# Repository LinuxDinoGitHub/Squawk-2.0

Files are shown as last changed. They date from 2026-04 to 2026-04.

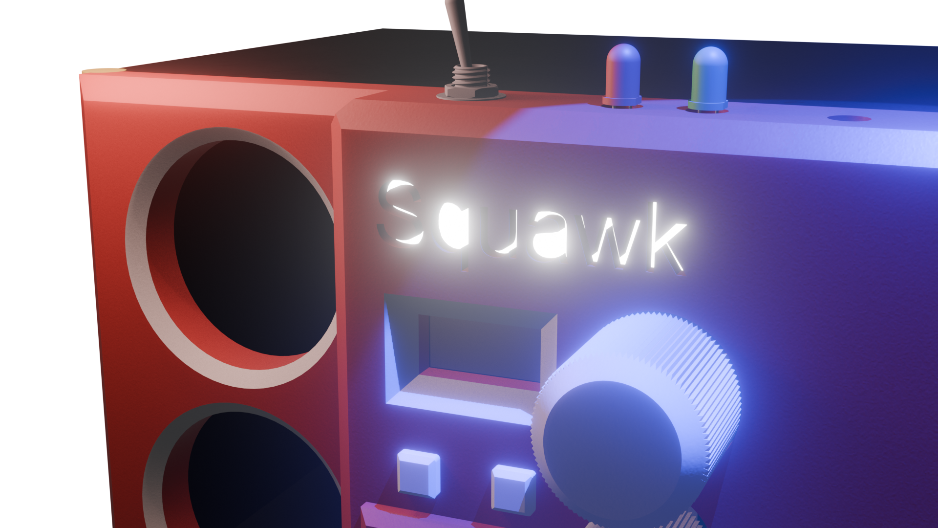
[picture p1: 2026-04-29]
Assets/Radio_corner.png

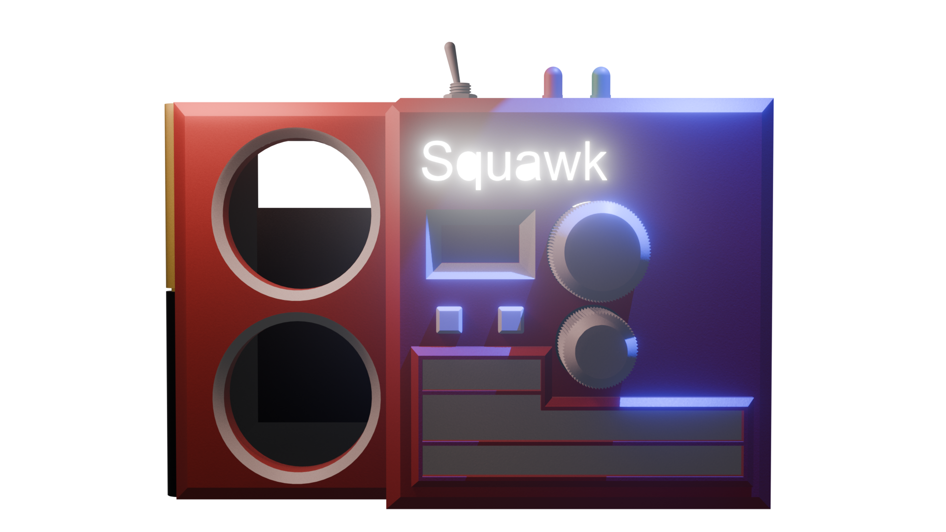
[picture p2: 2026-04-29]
Assets/Radio_front.png

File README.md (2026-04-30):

# Squawk-2.0
A radio station with a storage unit for walkie-talkies, w/ OLED screen & 3.5mm headphone jack connector
SI4844 powered with Arduino Nano, PAM8403 amplifier with the [pu2clr](https://pu2clr.github.io/SI4844/) library.

Radio-2026-04-28 000101
Radio-2026-04-28 000112

## About this project
The name "Squawk 2.0" originates from the popular TV show - Stranger Things (Season 5), where they had a master radio station for duplex transmission. Though this station cannot transmit any radio signals for walkie-talkies to pick up (due to legal reasons), it listens to the Citizens Band (CB) with 20 channels and a range of 2-3km. This is designed as a retro tabletop AM/FM/SW radio with the SI4844 chip, and also a handy storage device for the user. Planning to create walkie-talkies in the future that can connect to this station.
### Why did I make this?
Well, I needed a storage compartment for my walkie talkies and also wanted the container to be a bit more exciting than just a regular tin box. 

### How do you use it?
It's pretty simple, here is a layout of all the functions of the buttons you can press:


## Key features
- SW/MW/AM/FM radio broadcast with SI4844 IC
- Adjustable channel and volume with OLED screen indicator
- Storage compartment in 3D model
- Hinged door to access the compartment
- Arduino powered - open source code and customisable to your own liking
- USB-B connectivity
- 3.5mm headphone jack to listen to the radio independently without interrupting neighbours, like a Walkman
- Optimised 4-layer PCB (front, gnd_front, gnd_back, back) routing for good antenna connectivity

## [Schematic](https://github.com/LinuxDinoGitHub/Squawk-2.0/tree/main/pcb)
Print Schematic

## [PCB](https://github.com/LinuxDinoGitHub/Squawk-2.0/tree/main/pcb)
A simple, 4-layer PCB. 96mm x 81mm PCB with 3 mounting holes for M3 screws.
### First layer (Front)


### Second layer (GND net)


### Third layer (GND net)


### Fourth layer (Back)


### 3D view
Front

Back


## [Firmware](https://github.com/LinuxDinoGitHub/Squawk-2.0/blob/main/firmware/firmware.ino)
After assembling your PCB, use the firmware.ino file in the repository to flash your Arduino Nano. You can customise messages and timings by editing the code with the Arduino IDE.

## BOM
The BOM **without** specific values is linked here ([GitHub directory](https://github.com/LinuxDinoGitHub/Squawk-2.0/blob/main/BOM_kicad_generated.csv) or [Google Sheets](https://docs.google.com/spreadsheets/d/1nt2ZC4SuuWCHXpdcqgjWmxoxNzFQoS0aQbvXVXabcSM/edit?gid=0#gid=0). The total cost for the project should not exceed 13USD (after averaging costs out by dividing by the bulk bought quantity).

The BOM **with** specific values is here (Github [directory](https://github.com/LinuxDinoGitHub/Squawk-2.0/blob/main/BOM_with_links.csv) or [Google Sheets](https://docs.google.com/spreadsheets/d/1nt2ZC4SuuWCHXpdcqgjWmxoxNzFQoS0aQbvXVXabcSM/edit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))

### 3D printed case
Use a slicer to print the following [file](https://github.com/LinuxDinoGitHub/Squawk-2.0/blob/main/models/Radio.step). The 3D printed case is not accounted for in the BOM due to the variation between suppliers. The expected filament cost is around 10$ USD.

## Zine page


## Credits
Huge thanks to Ricardo for his amazing library and intuitive example code for the SI4844, which genuinely saved me so much time. [Link](https://pu2clr.github.io/SI4844/) to his repo and library. Thanks to the amazing community from Hack Club fallout for helping out my design as well, I couldn't have done it without them.

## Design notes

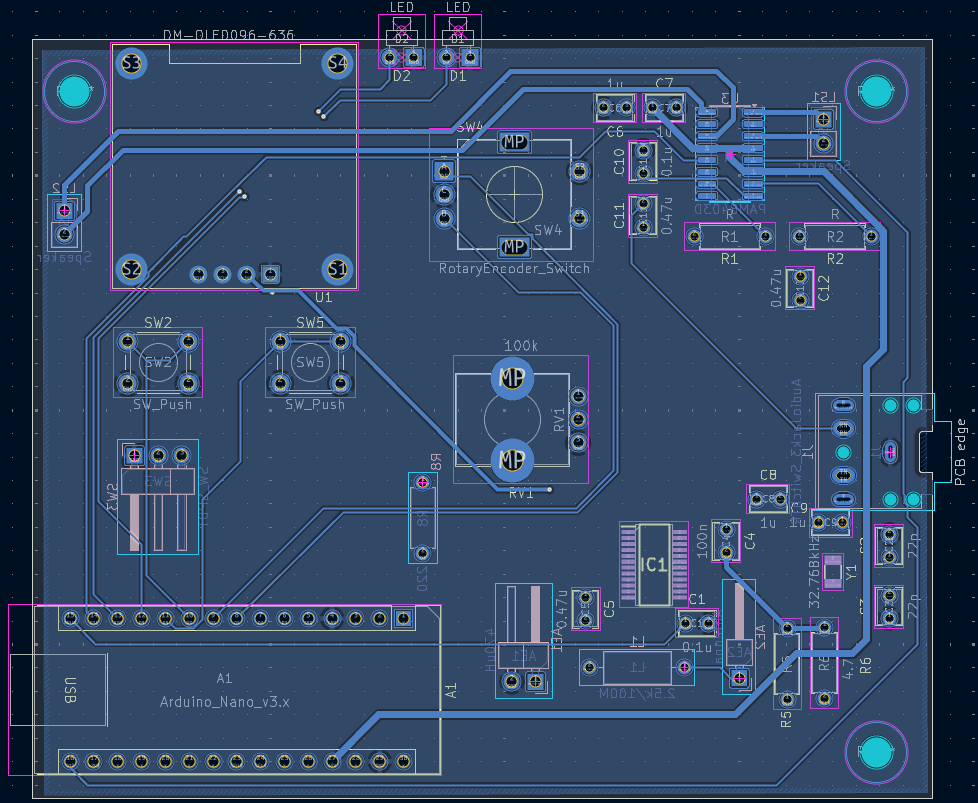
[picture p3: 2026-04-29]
Assets/Screenshot 2026-04-27 235309.png

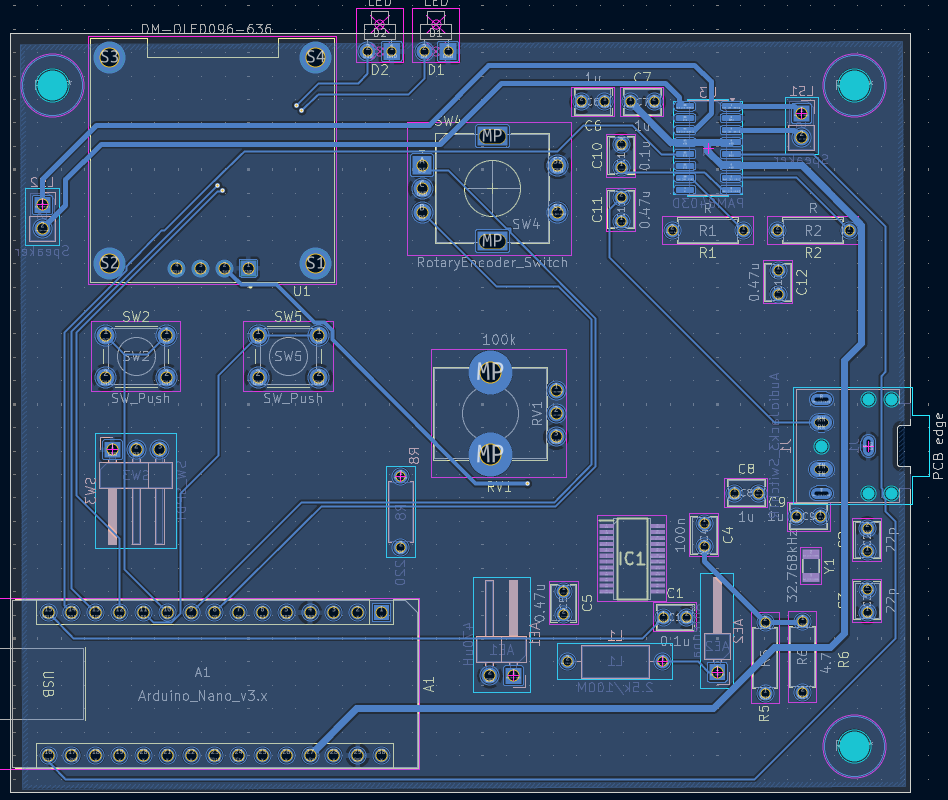
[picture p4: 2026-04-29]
Assets/Screenshot 2026-04-27 235300.png

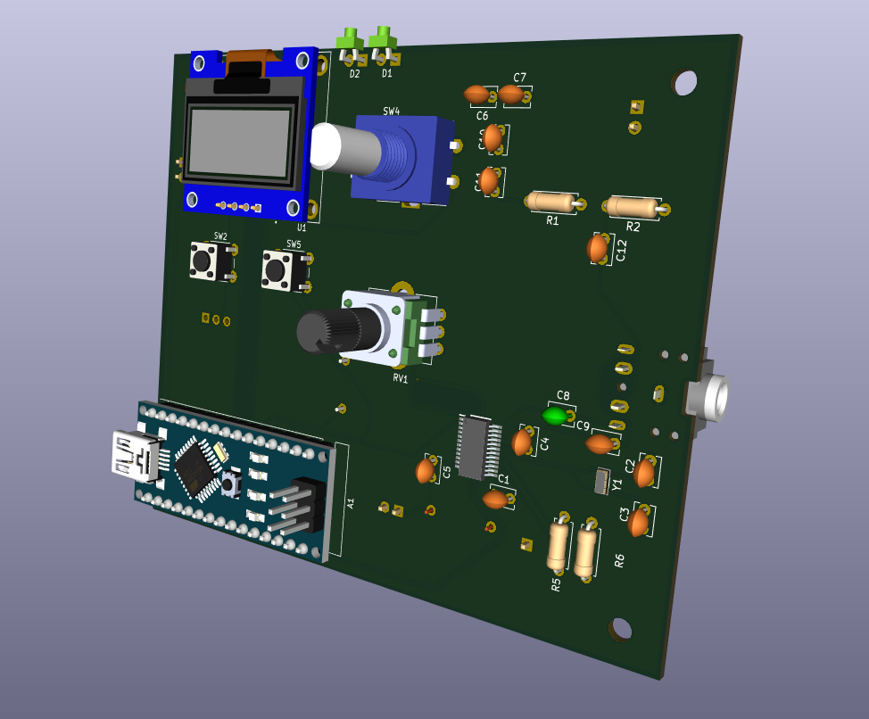
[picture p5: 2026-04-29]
Assets/Screenshot 2026-04-27 235516.png

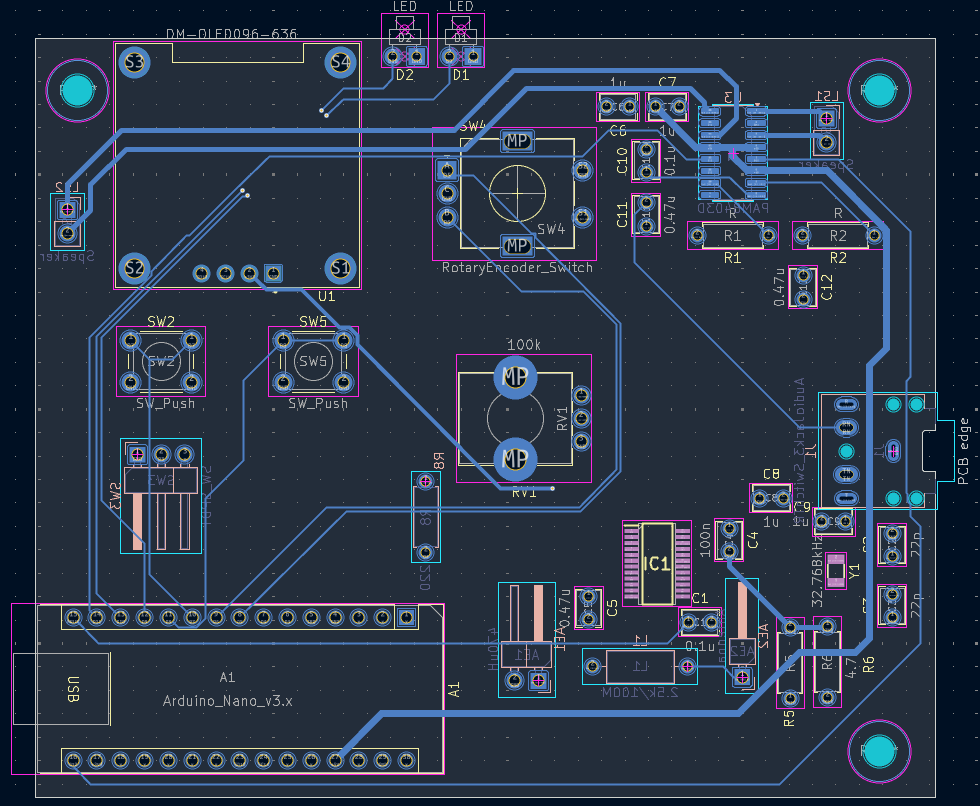
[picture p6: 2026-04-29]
Assets/Screenshot 2026-04-27 235333.png

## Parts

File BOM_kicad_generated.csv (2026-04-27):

Reference | Qty | Value | DNP | Exclude from BOM | Exclude from Board | Footprint | Datasheet
A1 | 1 | Arduino_Nano_v3.x |  |  |  | Module:Arduino_Nano | http://www.mouser.com/pdfdocs/Gravitech_Arduino_Nano3_0.pdf
AE1 | 1 | 470uH |  |  |  | Connector_PinHeader_2.54mm:PinHeader_1x02_P2.54mm_Horizontal
AE2 | 1 | Antenna |  |  |  | Connector_PinHeader_2.54mm:PinHeader_1x01_P2.54mm_Horizontal
C1,C10 | 2 | 0.1u |  |  |  | Capacitor_THT:C_Disc_D3.8mm_W2.6mm_P2.50mm
C2,C3 | 2 | 22p |  |  |  | Capacitor_THT:C_Disc_D3.8mm_W2.6mm_P2.50mm
C4 | 1 | 100n |  |  |  | Capacitor_THT:C_Disc_D3.8mm_W2.6mm_P2.50mm
C5,C11,C12 | 3 | 0.47u |  |  |  | Capacitor_THT:C_Disc_D3.8mm_W2.6mm_P2.50mm
C6,C7,C8,C9 | 4 | 1u |  |  |  | Capacitor_THT:C_Disc_D3.8mm_W2.6mm_P2.50mm
D1,D2 | 2 | LED |  |  |  | LED_THT:LED_D1.8mm_W1.8mm_H2.4mm_Horizontal_O1.27mm_Z1.6mm
IC1 | 1 | SI4844-B20-GUR |  |  |  | KiCad2:SOP64P600X175-24N | https://www.mouser.com/datasheet/2/472/Si4844_B20-2507496.pdf
J1 | 1 | AudioJack3_SwitchTR |  |  |  | Connector_Audio:Jack_3.5mm_CUI_SJ1-3525N_Horizontal
L1 | 1 | 2.5k/100M |  |  |  | Inductor_THT:L_Axial_L7.0mm_D3.3mm_P10.16mm_Horizontal_Fastron_MICC
LS1,LS2 | 2 | Speaker |  |  |  | Connector_PinHeader_2.54mm:PinHeader_1x02_P2.54mm_Vertical
R1,R2 | 2 | R |  |  |  | Resistor_THT:R_Axial_DIN0207_L6.3mm_D2.5mm_P7.62mm_Horizontal
R5,R6 | 2 | 4.7k |  |  |  | Resistor_THT:R_Axial_DIN0207_L6.3mm_D2.5mm_P7.62mm_Horizontal
R8 | 1 | 220 |  |  |  | Resistor_THT:R_Axial_DIN0207_L6.3mm_D2.5mm_P7.62mm_Horizontal
RV1 | 1 | 100k |  |  |  | Potentiometer_THT:Potentiometer_Bourns_PTV09A-1_Single_Vertical
SW2,SW5 | 2 | SW_Push |  |  |  | Button_Switch_THT:SW_PUSH_6mm
SW3 | 1 | SW_SPDT |  |  |  | Connector_PinHeader_2.54mm:PinHeader_1x03_P2.54mm_Horizontal
SW4 | 1 | RotaryEncoder_Switch |  |  |  | Rotary_Encoder:RotaryEncoder_Alps_EC11E-Switch_Vertical_H20mm
U1 | 1 | DM-OLED096-636 |  |  |  | DM-OLED096-636:MODULE_DM-OLED096-636
U3 | 1 | PAM8403D |  |  |  | Package_SO:SOIC-16_3.9x9.9mm_P1.27mm | https://www.diodes.com/assets/Datasheets/products_inactive_data/PAM8403.pdf
Y1 | 1 | 32.768kHz |  |  |  | Crystal:Crystal_SMD_3215-2Pin_3.2x1.5mm

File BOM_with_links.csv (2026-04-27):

Component | Quantity | Purchasing quantity | Price (HKD) | Average Price(HKD) | Link (Aliexpress)
Arduino nano | 1 | 1 | 15.63 | 15.63 | https://www.aliexpress.com/item/1005004904865598.html?curPageLogUid=vkYqpu5df7i1
Si4844 | 1 | 1 | 6.22 | 6.22 | https://www.aliexpress.com/item/1005009167191304.html?curPageLogUid=VBaIWKYVAlcq
Speaker | 2 | 2 | 14.69 | 14.69 | https://www.aliexpress.com/item/32963121430.html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
Audio jack | 1 | 10 | 13.21 | 1.32 | https://www.aliexpress.com/item/1005008243857446.html?curPageLogUid=lKPTrOS0Pi5D
Audio amp | 1 | 10 | 1.41 | 0.14 | https://www.aliexpress.com/item/1005004049958533.html?curPageLogUid=BbQga2S7KLyP
Ferrite rod antenna | 1 | 5 | 50.6 | 10.12 | https://www.aliexpress.com/item/4000125449068.html?scm_id=1007.40050.354490.0&scm-url=1007.40050.354490.0
FM antenna | 1 | 1 | 8.73 | 8.73 | https://www.aliexpress.com/item/1005004492932391.html?curPageLogUid=ljO8rNIAne0f
6mm tactile switch | 2 | 20 | 7 | 0.70 | https://www.aliexpress.com/item/33008621978.html?curPageLogUid=k7zHfLOsFU2o
5mm LEDs | 2 | 100 | 9.68 | 0.19 | https://www.aliexpress.com/item/1005008232913389.html?curPageLogUid=16FXfKzrMASL
Toggle switch | 1 | 1 | 3.85 | 3.85 | https://www.aliexpress.com/item/4000177976189.html?curPageLogUid=18NpcsBhdBTf
Variable resistor | 1 | 10 | 3.22 | 0.32 | https://www.aliexpress.com/item/1005003276146441.html?curPageLogUid=0bzzIlN6npLy
OLED Display 0.96 inch | 1 | 1 | 9.99 | 9.99 | https://www.aliexpress.com/item/1005006385950490.html?curPageLogUid=9HJrmzL4Pr96
Resistors | 10 | 300 | 16.15 | 0.54 | https://www.aliexpress.com/item/1005011772534173.html?curPageLogUid=68fhdKCqYf9S
Capacitors (0.1u, 22p, 100n, 0.47u, 1u) | 12 | 500 | 40.2 | 0.96 | https://www.aliexpress.com/item/1005002513813451.html?curPageLogUid=eFP2b91R6ocB
Rotary encoder | 1 | 1 | 4.88 | 4.88 | https://www.aliexpress.com/item/1005007644083514.html?curPageLogUid=689RurIsD01g
Crystal 32.768kHz | 1 | 10 | 5.74 | 0.57 | https://www.aliexpress.com/item/1005004765596465.html?curPageLogUid=2FnkTeJsL6hJ
PCB (no shipping) | 1 | 5 | 54.6 | 10.92
Total |  |  | 211.2 | 89.78

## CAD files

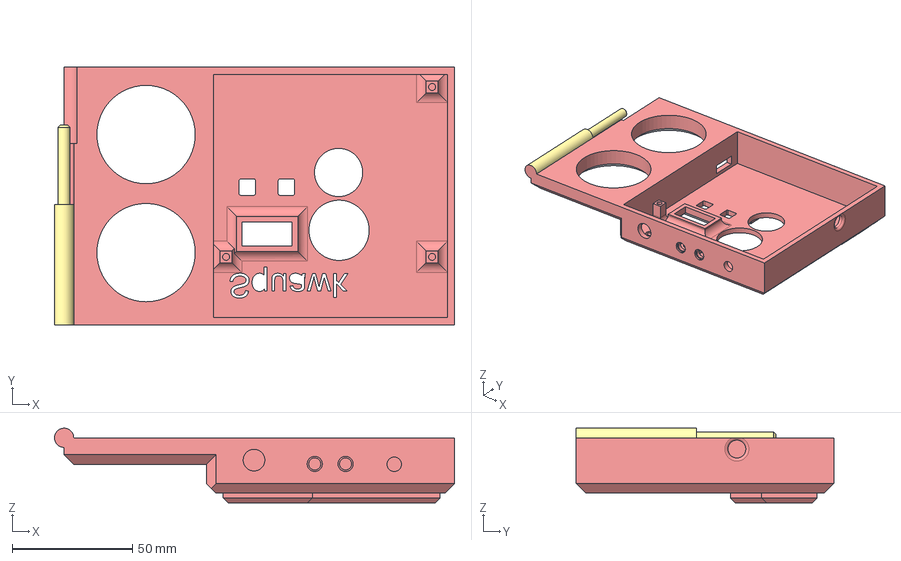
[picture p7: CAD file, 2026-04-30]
models/front_cover.step
166.0 x 107.0 x 31.0 mm

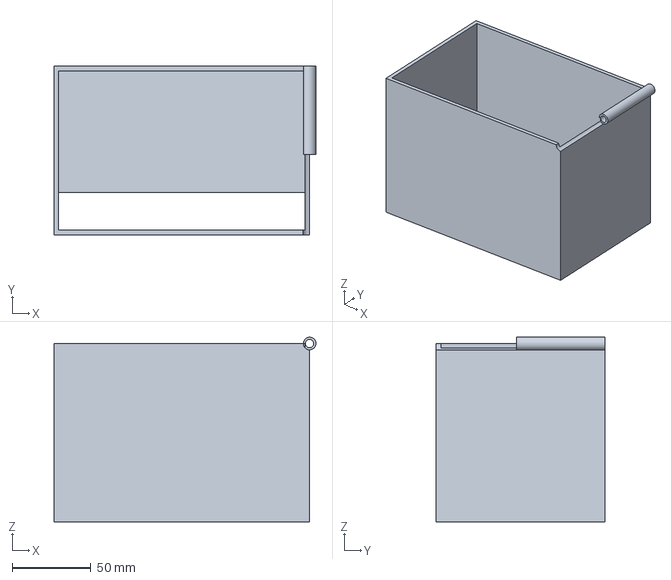
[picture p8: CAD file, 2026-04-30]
models/back_container.step
166.0 x 107.0 x 117.0 mm

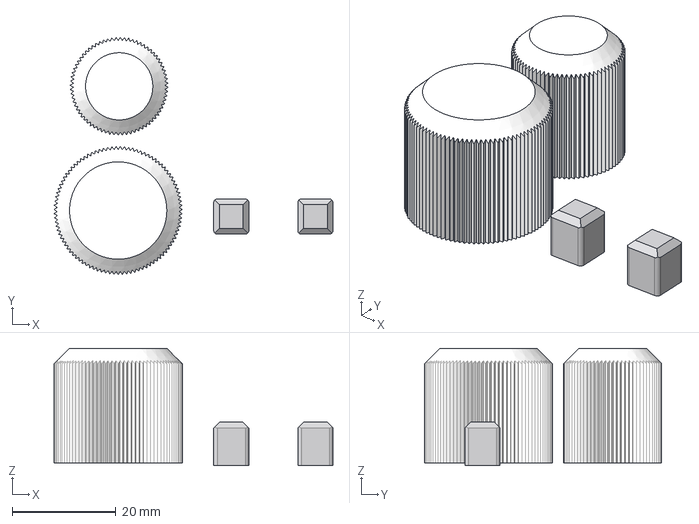
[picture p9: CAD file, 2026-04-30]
models/knobs_buttons.step
53.9 x 45.9 x 22.7 mm

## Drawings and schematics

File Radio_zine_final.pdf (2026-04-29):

# W S Q K Th e Squawk

# Linus, 15, Hong Kong

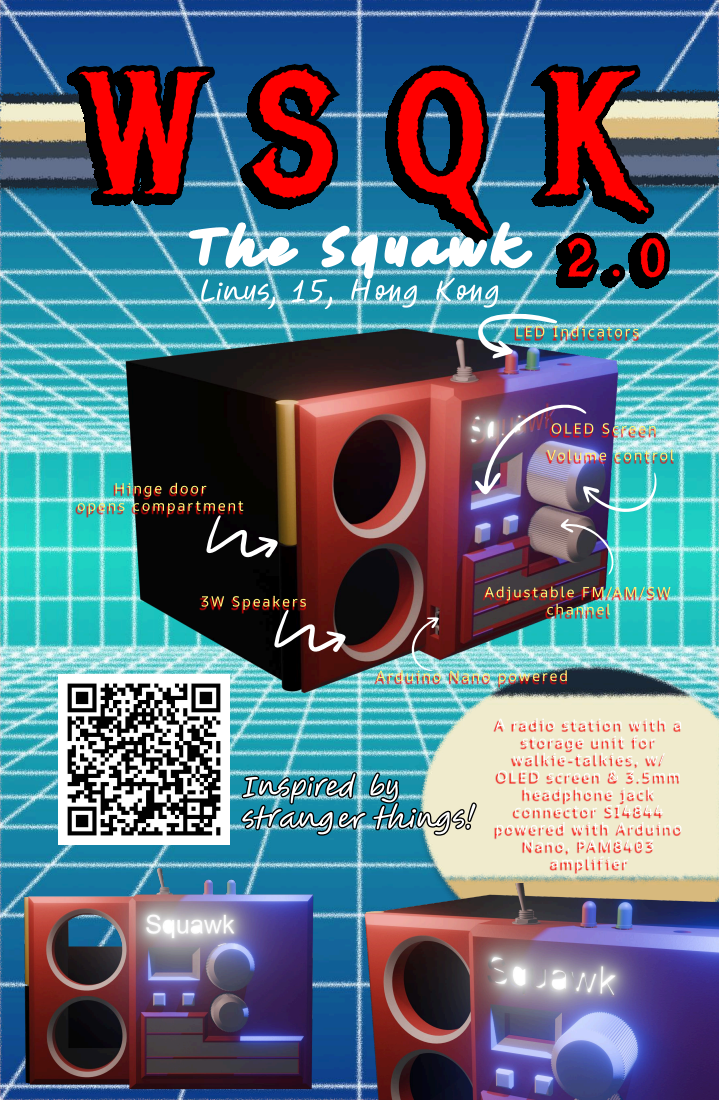
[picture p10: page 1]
O LED S cre e n; A d jus t a b l e FM /AM /SW; Inspired by stranger things!

LED In d i c a to rs

O LED s cre e n & 3.5mm
N a n o, PAM8403

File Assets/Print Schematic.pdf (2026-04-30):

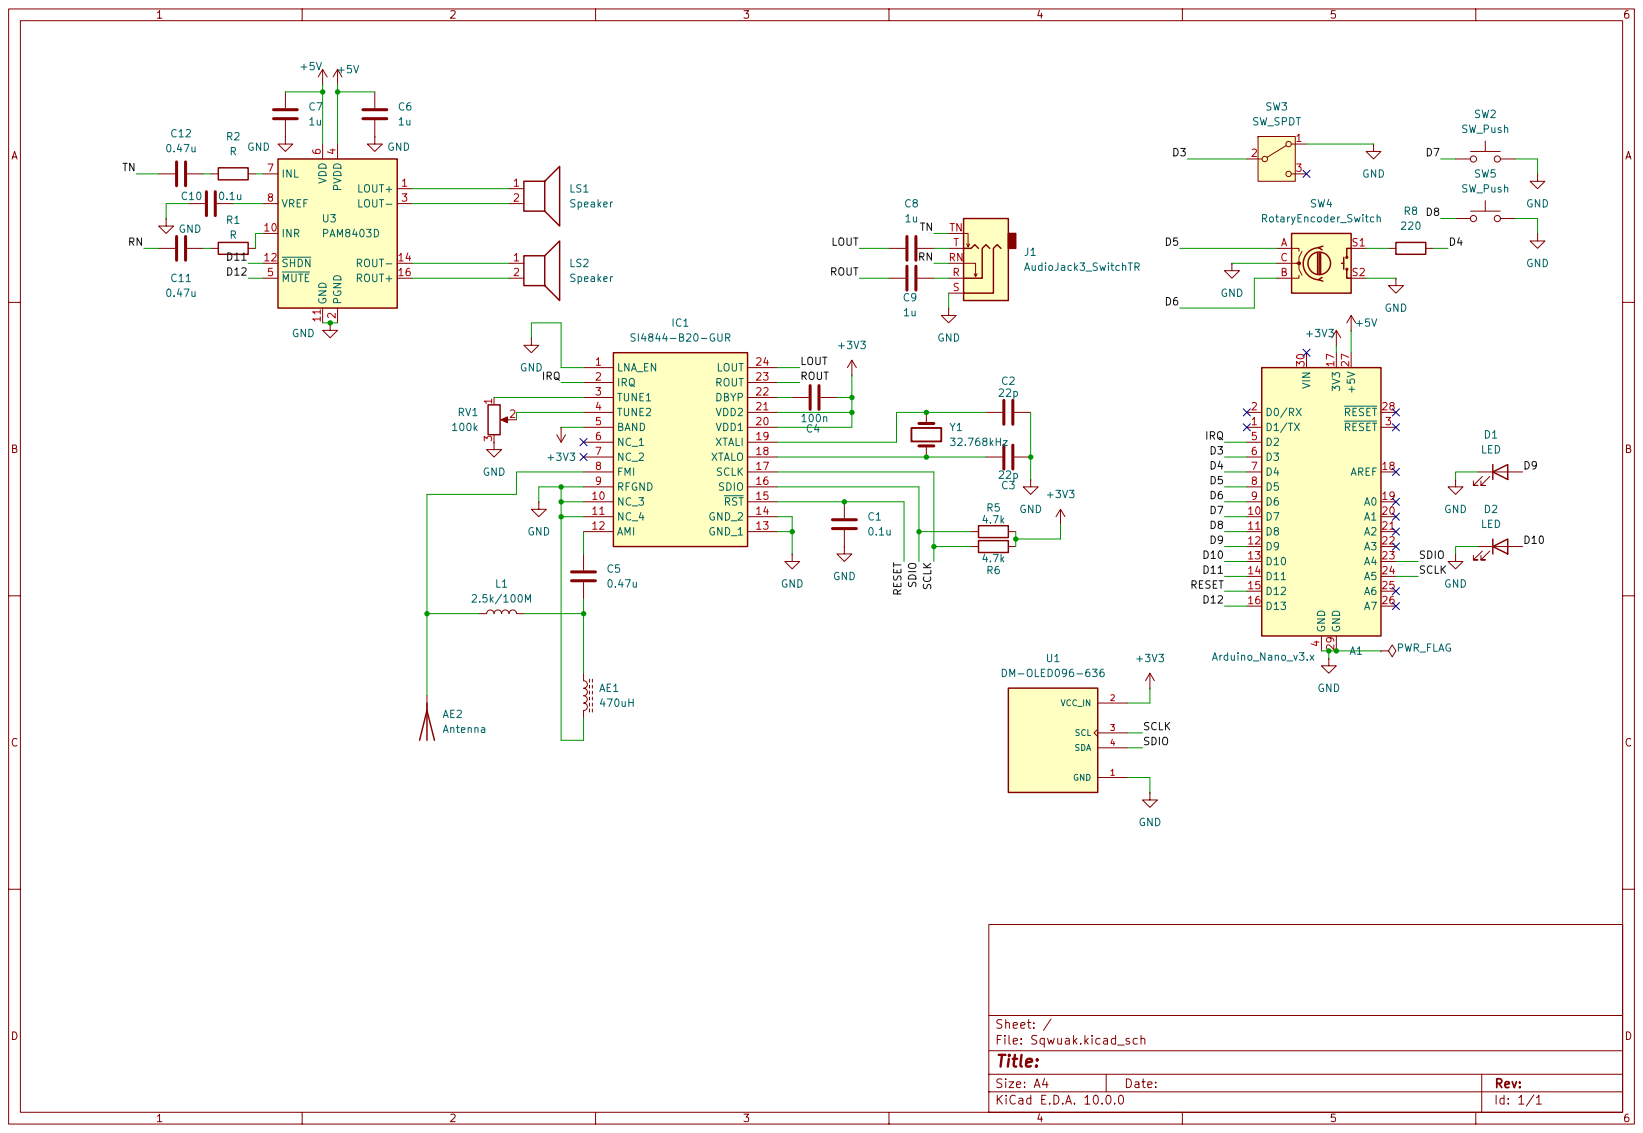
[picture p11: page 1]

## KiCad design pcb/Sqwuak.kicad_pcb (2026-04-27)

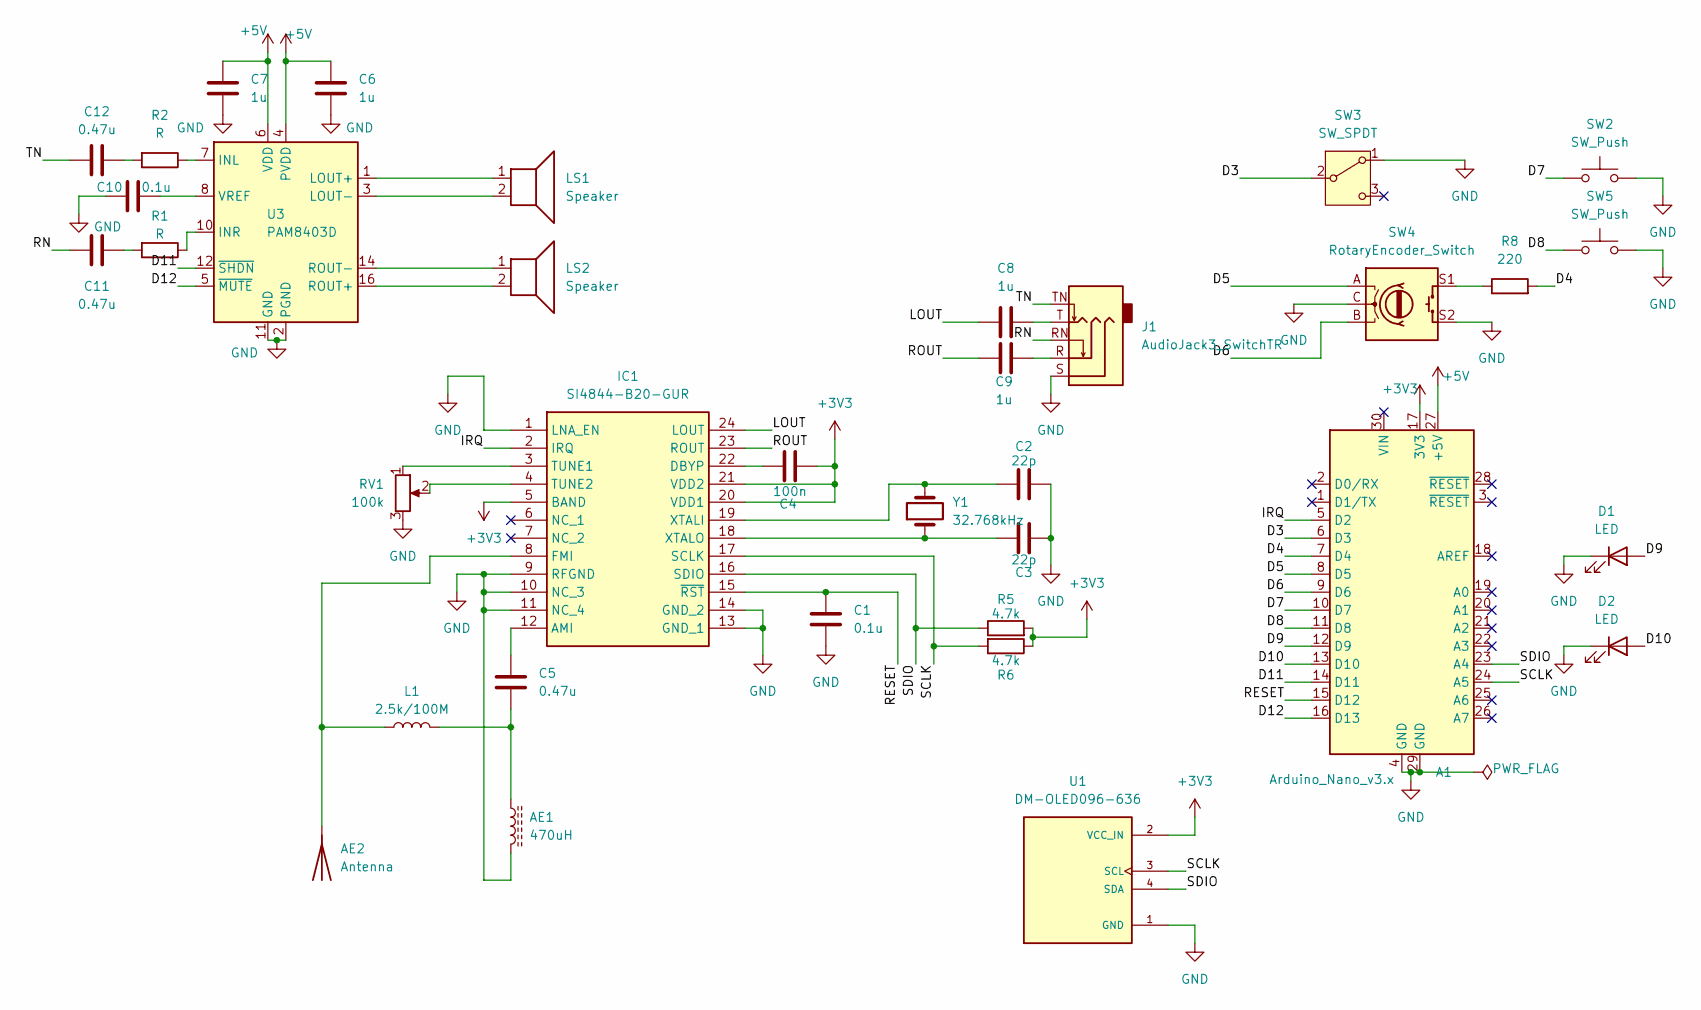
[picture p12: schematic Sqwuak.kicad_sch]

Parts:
A1: Arduino_Nano_v3.x; Arduino_Nano
AE1: 470uH; PinHeader_1x02_P2.54mm_Horizontal
AE2: Antenna; PinHeader_1x01_P2.54mm_Horizontal
C1, C10: 0.1u; C_Disc_D3.8mm_W2.6mm_P2.50mm
C2, C3: 22p; C_Disc_D3.8mm_W2.6mm_P2.50mm
C4: 100n; C_Disc_D3.8mm_W2.6mm_P2.50mm
C5, C11, C12: 0.47u; C_Disc_D3.8mm_W2.6mm_P2.50mm
C6, C7, C8, C9: 1u; C_Disc_D3.8mm_W2.6mm_P2.50mm
D1, D2: LED; LED_D1.8mm_W1.8mm_H2.4mm_Horizontal_O1.27mm_Z1.6mm
IC1: SI4844-B20-GUR; SOP64P600X175-24N; Manufacturer_Part_Number SI4844-B20-GUR; Mouser Part Number 634-SI4844-B20-GUR
J1: AudioJack3_SwitchTR; Jack_3.5mm_CUI_SJ1-3525N_Horizontal
L1: 2.5k/100M; L_Axial_L7.0mm_D3.3mm_P10.16mm_Horizontal_Fastron_MICC
LS1, LS2: Speaker; PinHeader_1x02_P2.54mm_Vertical
R1, R2: R; R_Axial_DIN0207_L6.3mm_D2.5mm_P7.62mm_Horizontal
R5, R6: 4.7k; R_Axial_DIN0207_L6.3mm_D2.5mm_P7.62mm_Horizontal
R8: 220; R_Axial_DIN0207_L6.3mm_D2.5mm_P7.62mm_Horizontal
RV1: 100k; Potentiometer_Bourns_PTV09A-1_Single_Vertical
SW2, SW5: SW_Push; SW_PUSH_6mm
SW3: SW_SPDT; PinHeader_1x03_P2.54mm_Horizontal
SW4: RotaryEncoder_Switch; RotaryEncoder_Alps_EC11E-Switch_Vertical_H20mm
U1: DM-OLED096-636; MODULE_DM-OLED096-636; PARTREV 2018-09-10
U3: PAM8403D; SOIC-16_3.9x9.9mm_P1.27mm
Y1: 32.768kHz; Crystal_SMD_3215-2Pin_3.2x1.5mm

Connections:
+3V3: A1.17 (3V3), C4.2, IC1.5 (BAND), IC1.20 (VDD1), IC1.21 (VDD2), R5.2, R6.1, U1.2 (VCC_IN)
+5V: A1.27 (+5V), C6.1, C7.1, U3.4 (PVDD), U3.6 (VDD), U3.13 (PVDD)
/D3: A1.6 (D3), SW3.2 (B)
/D4: A1.7 (D4), R8.2
/D5: A1.8 (D5), SW4.A
/D6: A1.9 (D6), SW4.B
/D7: A1.10 (D7), SW2.1
/D8: A1.11 (D8), SW5.1
/D9: A1.12 (D9), D1.2 (A)
/D10: A1.13 (D10), D2.2 (A)
/D11: A1.14 (D11), U3.12 (~SHDN)
/D12: A1.16 (D13), U3.5 (~MUTE)
/IRQ: A1.5 (D2), IC1.2 (IRQ)
/LOUT: C8.1, IC1.24 (LOUT)
/RESET: A1.15 (D12), C1.1, IC1.15 (~RST)
/RN: C11.2, J1.RN
/ROUT: C9.2, IC1.23 (ROUT)
/SCLK: A1.24 (A5), IC1.17 (SCLK), R6.2, U1.3 (SCL)
/SDIO: A1.23 (A4), IC1.16 (SDIO), R5.1, U1.4 (SDA)
/TN: C12.2, J1.TN
GND: A1.4 (GND), A1.29 (GND), AE1.2, C1.2, C2.2, C3.1, C6.2, C7.2, C10.2, D1.1 (K), D2.1 (K), IC1.1 (LNA_EN), IC1.9 (RFGND), IC1.10 (NC_3), IC1.11 (NC_4), IC1.13 (GND_1), IC1.14 (GND_2), J1.S, RV1.3, SW2.2, SW3.1 (A), SW4.C, SW4.S2, SW5.2, U1.1 (GND), U3.2 (PGND), U3.11 (GND), U3.15 (PGND)
unnamed: AE1.1, C5.2, L1.2
unnamed: AE2.1 (A_1), IC1.8 (FMI), L1.1
unnamed: C8.2, J1.T
unnamed: C9.1, J1.R
unnamed: C11.1, R1.2
unnamed: C12.1, R2.2
unnamed: C5.1, IC1.12 (AMI)
unnamed: C4.1, IC1.22 (DBYP)
unnamed: IC1.3 (TUNE1), RV1.1
unnamed: IC1.4 (TUNE2), RV1.2
unnamed: C2.1, IC1.19 (XTALI), Y1.2
unnamed: C3.2, IC1.18 (XTALO), Y1.1
unnamed: R8.1, SW4.S1
unnamed: R2.1, U3.7 (INL)
unnamed: R1.1, U3.10 (INR)
unnamed: LS1.1, U3.1 (LOUT+)
unnamed: LS1.2, U3.3 (LOUT-)
unnamed: LS2.2, U3.16 (ROUT+)
unnamed: LS2.1, U3.14 (ROUT-)
unnamed: C10.1, U3.8 (VREF)

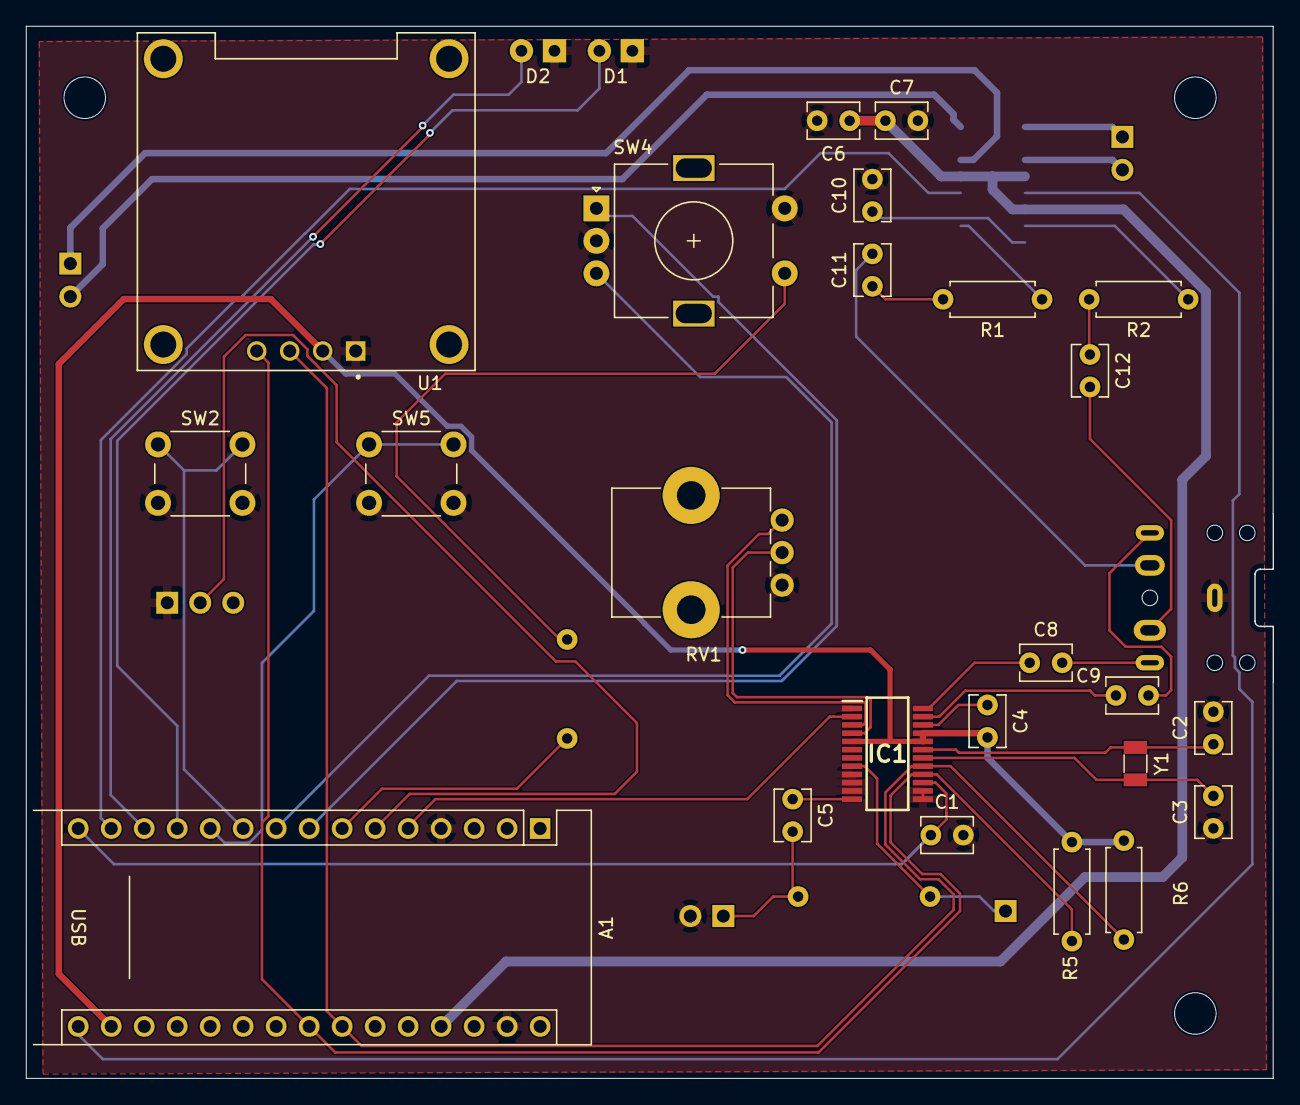
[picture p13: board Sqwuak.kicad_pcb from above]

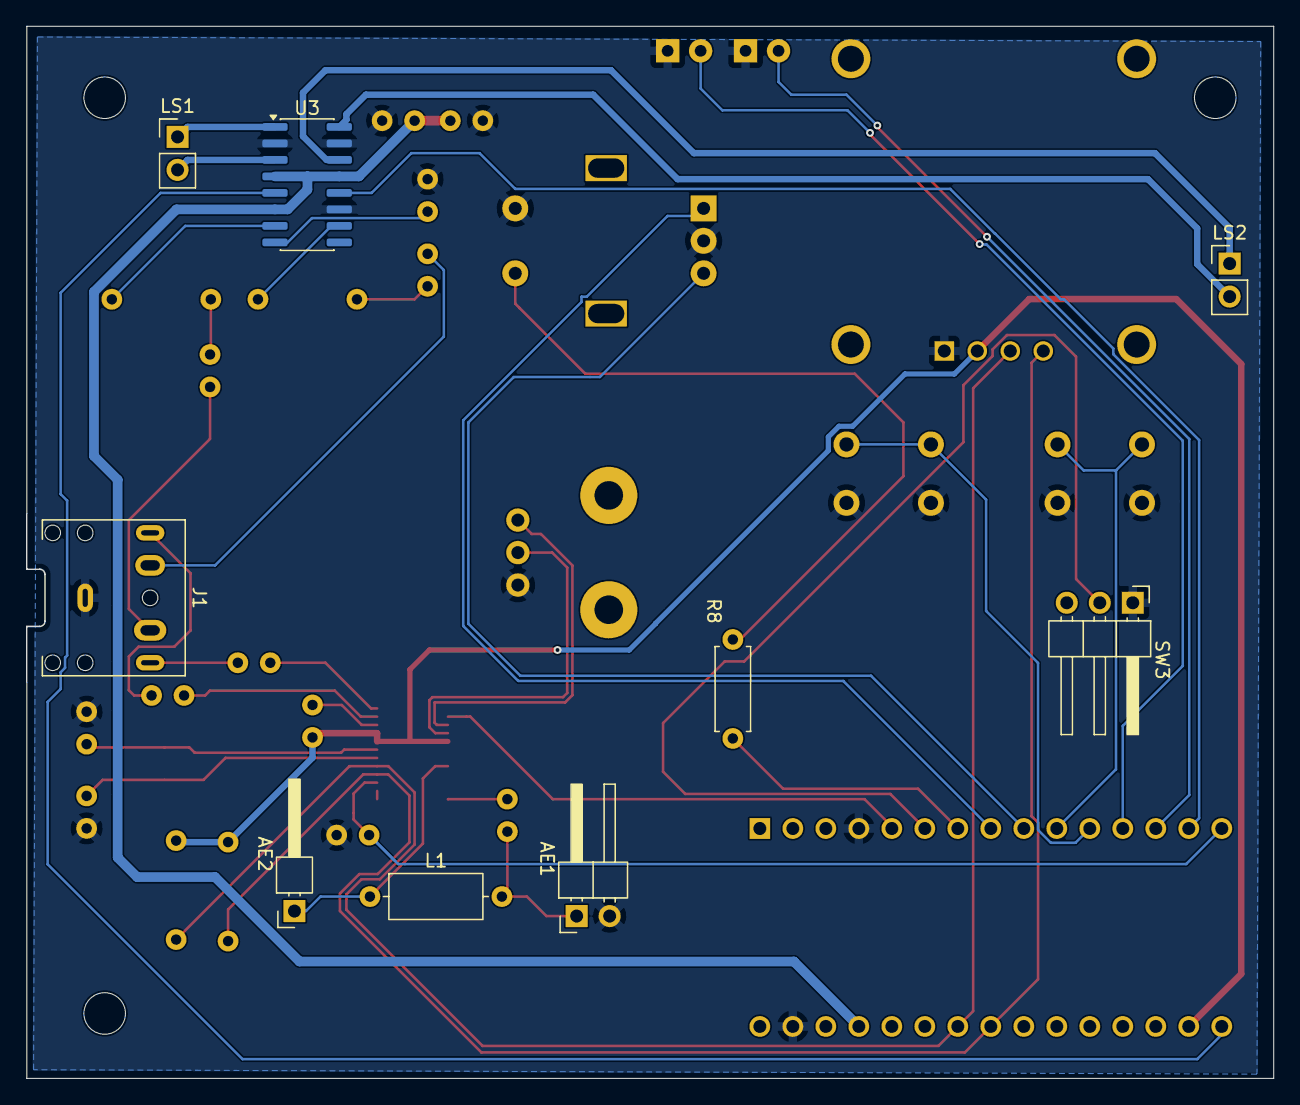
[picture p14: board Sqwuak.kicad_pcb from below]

Board: 2 copper layers, 96.0 x 81.0 mm, 35 parts (9 on the bottom side), 41 nets.

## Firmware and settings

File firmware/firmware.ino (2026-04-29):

#include <SI4844.h>
#include <Adafruit_GFX.h>
#include <Adafruit_SSD1306.h>
#include <EEPROM.h> 

// OLED
#define I2C_ADDRESS 0x3C
#define RST_PIN -1
// Arduino
#define INTERRUPT_PIN 2
#define RESET_PIN 12

//Volume control pins
#define BAND_UP 7    // Next Band
#define BAND_DOWN 8  // Previous Band
#define VOL_UP 5    // Volume Volume Up
#define VOL_DOWN 6  // Volume Down
#define VOL_PU_RES 4

#define MIN_ELAPSED_TIME 100

// EEPROM - don't change this
const uint8_t app_id = 27;
const int eeprom_address = 0;

long elapsedButton = millis();
// The following code is from Ricardo's library, all credits to him
typedef struct {
  int8_t bandIdx;
  uint16_t botton;    // botton frequency (10350 = 103.5Mhz; 9775 = 9,775 kHz)
  uint16_t top;       // top
  uint8_t bandSpace;  // FM only (10 = 100 kHz; 20 = 200 kHz)
  char *desc; 
} Band;

/*
  To add, remove, or modify a band, simply update the table below. Each row corresponds to a specific band. 
  Here's how the parameters are defined:

  1) First parameter: An internal value used by the SI474X to identify the band (see the Datasheet AN610 - Si48XX ATDD PROGRAMMING GUIDE page 17).
  2) Second and third parameters: These specify the lower and upper frequency limits for the band:
  3) For FM bands, the values are in MHz (e.g., 7700 means 77.00 MHz, and 10800 means 108.00 MHz).
  4) For SW bands, the values are in kHz (e.g., 4600 means 4,600 kHz or 4.6 MHz).
  5) If both frequencies are set to 0, the device will use its default internal frequencies for that band.
  6) Fourth parameter: Defines the frequency step size:
  7) For FM: 10 corresponds to 100 kHz spacing, and 20 corresponds to 200 kHz spacing.
  8) For SW: 5 corresponds to 5 kHz spacing.
  9) Fifth parameter: A descriptive name for the band, making it easier to identify.

  In the following example, except for the MW1 and MW2 bands, all bands have been customized and do not follow the SI48XX device's internal defaults. 
  Based on the datasheet "AN610 - Si48XX ATDD PROGRAMMING GUIDE" pages 17 and 18, you can select additional bands or configure them according to 
  your preferences.

  Note that in the following example, the FM bands have been configured to be narrower than those typically found in commercial receivers. 
  This approach was adopted to enhance the tuning experience. By narrowing the bands, it became easier to tune a station using a 100K potentiometer, 
  which offers only 180 degrees of rotation. Commercial receivers usually employ mechanical reduction systems, such as pulleys or gears, to improve 
  the user experience by providing finer tuning control. Since this prototype lacks such mechanical aids, I chose to narrow the bands to compensate 
  and optimize usability.

*/
Band tabBand[] = { { 3, 8700, 10810, 20, (char *) "FM " },      
                   { 20, 0,0,0, (char *) "MW1" },             
                   { 21, 0,0,0, (char *) "MW2" }, 
                   { 25, 4600, 5200,5, (char *) "60m" },
                   { 26, 5700, 6200,5, (char *) (char *) "49m"},
                   { 27, 7100, 7600,5, (char *) "41m"},
                   { 29, 9200, 9990,5, (char *) "31m"},
                   { 31, 11400,12200, 5, (char *) "25m"},
                   { 33, 13400,13990, 5, (char *) "22m"},
                   { 35, 15090,15700, 5, (char *) "19m"},
                   { 38, 17400,17990, 5, (char *) "16m"},
                   { 40, 21400,21790, 5, (char *) "13m" } };

const int8_t lastBand = (sizeof tabBand / sizeof(Band)) - 1;
int8_t bandIdx = 0;

// OLED - Declaration for a SSD1306 display connected to I2C (SDA, SCL pins)
Adafruit_SSD1306 display = Adafruit_SSD1306(128, 32, &Wire);

SI4844 si4844;

//For rotary encoder
int counter = 0;
int aState;
int aLastState;

void setup() {
  // put your setup code here, to run once:
  pinMode(BAND_UP, INPUT_PULLUP);
  pinMode(BAND_DOWN, INPUT_PULLUP);
  pinMode(VOL_UP, INPUT_PULLUP);
  pinMode(VOL_DOWN, INPUT_PULLUP);
  // rotary encoder setup
  aLastState = digitalRead(VOL_UP);   

  delay(150); 
  display.begin(SSD1306_SWITCHCAPVCC, I2C_ADDRESS);
  display.clearDisplay();
  display.display();
  display.setTextColor(SSD1306_WHITE);

  display.setCursor(0,0);
  display.print((char *)"Squawk Radio\n\nby LinuxDino");
  display.display();

  if (digitalRead(BAND_UP) == LOW)
  {
    EEPROM.update(eeprom_address, 0);
    display.setCursor(0,0);
    display.print((char *)"EEPROM RESET");
    delay(1500);
  }

  // Some crystal oscillators may need more time to stabilise. Uncomment the following line if you are experiencing issues starting the receiver.
  // si4844.setCrystalOscillatorStabilizationWaitTime(1);
  si4844.setup(RESET_PIN, INTERRUPT_PIN, -1, 100000);

  if (EEPROM.read(eeprom_address) == app_id)
    readAllReceiverInformation();
  else
    si4844.setVolume(60);
  

  if ( tabBand[bandIdx].botton != 0)
    si4844.setCustomBand(tabBand[bandIdx].bandIdx, tabBand[bandIdx].botton, tabBand[bandIdx].top,tabBand[bandIdx].bandSpace);
  else 
    si4844.setBand(tabBand[bandIdx].bandIdx);  

  displayDial();
}

void saveAllReceiverInformation() // Saves the stored volume
{
  EEPROM.update(eeprom_address, app_id);          
  EEPROM.update(eeprom_address + 1, si4844.getVolume()); 
  EEPROM.update(eeprom_address + 2, bandIdx);
}

void readAllReceiverInformation() // Gets the stored volume
{
  si4844.setVolume(EEPROM.read(eeprom_address + 1)); 
  bandIdx = EEPROM.read(eeprom_address + 2);

}

uint32_t oldFrequency = 0;
uint8_t oldStatusStationIndicator = 9;

void displayDial()
{
  String unit, freqDisplay, stereo;

  uint32_t currentFrequency = si4844.getFrequencyInteger();
  uint8_t currentStatusStationIndicator = si4844.getStatusStationIndicator() ;

  if ( oldFrequency == currentFrequency && oldStatusStationIndicator ==  currentStatusStationIndicator )
    return;

  oldFrequency = currentFrequency;
  oldStatusStationIndicator = currentStatusStationIndicator;

  if (si4844.getFrequencyInteger() > 999) 
    unit = (char *) "MHZ";
  else
    unit = (char *) "kHz";  

  display.setFont(NULL);
  display.clearDisplay();
  display.setCursor(3, 0);
  display.print(si4844.getBandMode());
  display.setCursor(48, 0);  
  if ( si4844.getStatusStationIndicator() != 0) 
    display.print("OK");
  else 
    display.print("  ");

  display.setCursor(105, 0);  
  display.print(tabBand[bandIdx].desc);
  display.setCursor(16, 31);
  display.print(si4844.getFormattedFrequency(2,'.'));
  display.setCursor(104, 30);
  display.setFont(NULL);
  display.print(" ");
  display.print(unit);
  
  if ( si4844.getStatusBandMode() == 0) { // Stereo/Mono with the band mode, but this project doesn't use the band switch so this part will be set automatically
    display.setCursor(75, 25);
    if (si4844.getStatusStereo() == 1)
      display.print("Stereo");
    else   
      display.print("Mono  ");
  }
  display.display();
}

void setBand(byte cmd)
{
  if (cmd == '+')
    bandIdx = (bandIdx < lastBand) ? (bandIdx + 1) : 0;
  else
    bandIdx = (bandIdx > 0) ? (bandIdx - 1) : lastBand;

  if ( tabBand[bandIdx].botton != 0)
    si4844.setCustomBand(tabBand[bandIdx].bandIdx, tabBand[bandIdx].botton, tabBand[bandIdx].top,tabBand[bandIdx].bandSpace);
  else 
    si4844.setBand(tabBand[bandIdx].bandIdx);  

  saveAllReceiverInformation();
  elapsedButton = millis();

}

void setVolume( char v) {
  si4844.changeVolume(v);
  elapsedButton = millis();
}

//Main code here that loops
void loop() {
  //Rotary encoder
  aState = digitalRead(VOL_UP);
  if ( (millis() - elapsedButton) > MIN_ELAPSED_TIME ) {
    if (digitalRead(BAND_UP) == LOW )
      setBand('+');
    else if (digitalRead(BAND_DOWN) == LOW )
      setBand('-');
    else if (digitalRead(VOL_DOWN) != aState)
      setVolume('-');
    else if (digitalRead(VOL_UP) == aState)
      setVolume('+');
  }
  
  if (si4844.hasStatusChanged())
    displayDial();
  aLastState = aState; // Updates the previous state of the outputA with the current state
  delay(10);
}

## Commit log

2026-04-14 Update README with project details and schematic
    Expanded project description and added schematic and BOM sections.
2026-04-15 Added schematic files just to backup
    [Sqwuak.kicad_pcb, Sqwuak.kicad_sch]
2026-04-27 Finished all files
    [Sqwuak-B_Cu.gbl, Sqwuak-B_Mask.gbs, Sqwuak-B_Paste.gbp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]
2026-04-27 Update README with project details and features
    Expanded project description and added key features, schematic, PCB details, firmware instructions, and BOM links.
2026-04-27 Added 3D models and BOM
    [BOM_kicad_generated.csv, BOM_with_links.csv]
2026-04-27 Update BOM links in README.md
2026-04-29 renamed a whole lotta file names
    [BOM_kicad_generated.csv, BOM_with_links.csv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]
2026-04-30 added step files for individual 3D printing
    [BOM_kicad_generated.csv, BOM_with_links.csv, back_container.step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]
2026-04-30 Replace schematic image with updated version
    Updated schematic image in README with new dimensions.
2026-04-30 Revise BOM section in README
    Updated BOM section with links to specific and non-specific values.
2026-04-30 added assets for the schematic
2026-05-09 zipped gerbers
    [Sqwuak-B_Cu.gbl, Sqwuak-B_Mask.gbs, Sqwuak-B_Paste.gbp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]
